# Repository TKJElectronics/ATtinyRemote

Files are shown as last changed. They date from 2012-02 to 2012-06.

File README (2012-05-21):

The code is released under the GNU General Public License.

This is a remote translator based on an ATtiny85. It translates commands from a Panasonic remote to specific JVC commands. This enables me to turn my JVC stereo on and off, mute it and turn the volume up or down, using my Panasonic remote for my TV.

A new version is now available, it can be found in the /ATtinyRemoteVer2 folder.

For more information see my blog post: http://blog.tkjelectronics.dk/2012/03/attinyremote/ or send me an email at kristianl at tkjelectronics dot dk.

The receiving code is based around Adafruit's IR-Commander sketch: https://github.com/adafruit/IR-Commander while the decoding of the Panasonic protocol and sending of the JVC commands are based upon this forked library: https://github.com/zenwheel/Arduino-IRremote. The originally library is by Ken Shirriff: https://github.com/shirriff/Arduino-IRremote

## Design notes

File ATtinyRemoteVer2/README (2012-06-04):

The code is released under the GNU General Public License.

This is a highly optimized version of the firmware. The code flow is basically the same as the first release.

The major difference is that it now uses a external interrupt for the receiving part. To tell the time I use timer0. It is used in CTC (Clear Timer on Compare Match Mode) every 6ms, as the maximum pulse i approximately 5ms. As the Panasonic protocol is very long (48 bits) is not necessary to check the length of the pulses very precisely, as my other IR remotes protocols' are only maximum 32 bits long. But it wouldn't be that hard to modify the code to work with any IR protocol.

Timer1 is used to send the IR commands. It is used in PWM mode, at a modulation frequency of 38kHz, but this can easily be modified.

I have also implemented a optional sleep mode, to save power consumption. This will set the microcontroller in power down mode.

For more information see my blog post: http://blog.tkjelectronics.dk/2012/03/attinyremote/ or send me an email at kristianl at tkjelectronics dot dk.

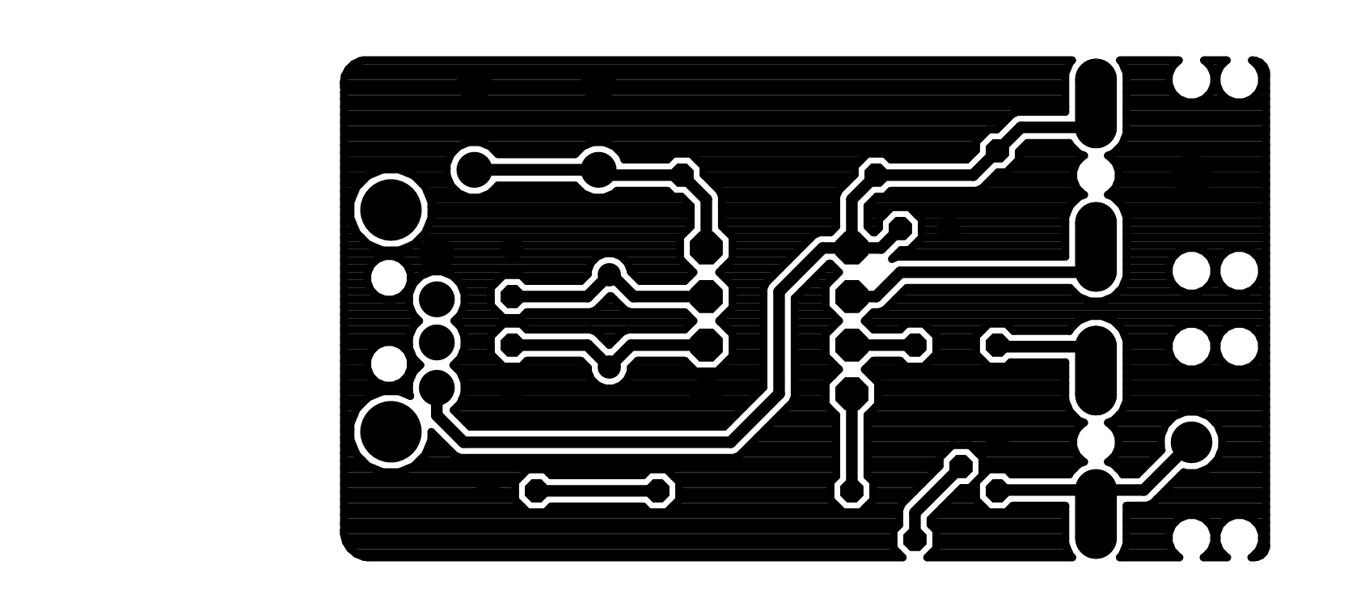
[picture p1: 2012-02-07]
PCB/Images for Gerber files/ATtinyRemote.bottomlayer.ger.png

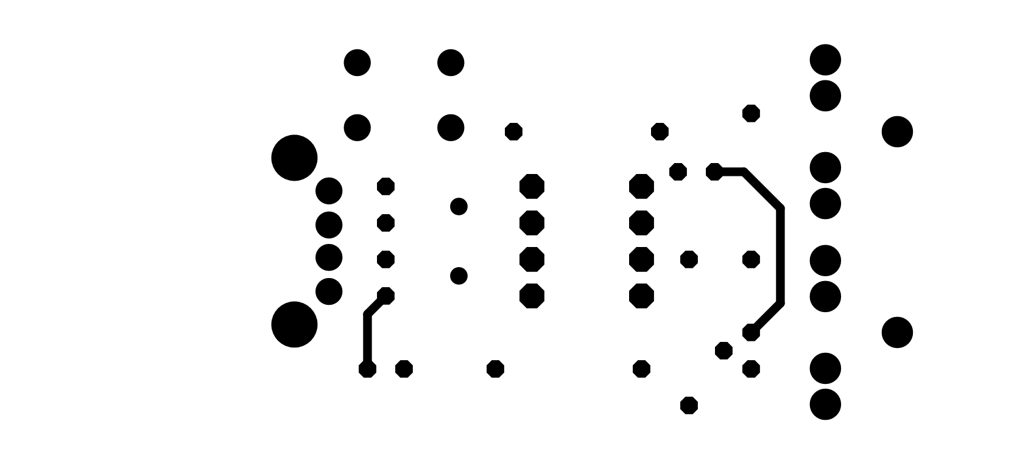
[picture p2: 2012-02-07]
PCB/Images for Gerber files/ATtinyRemote.toplayer.ger.png

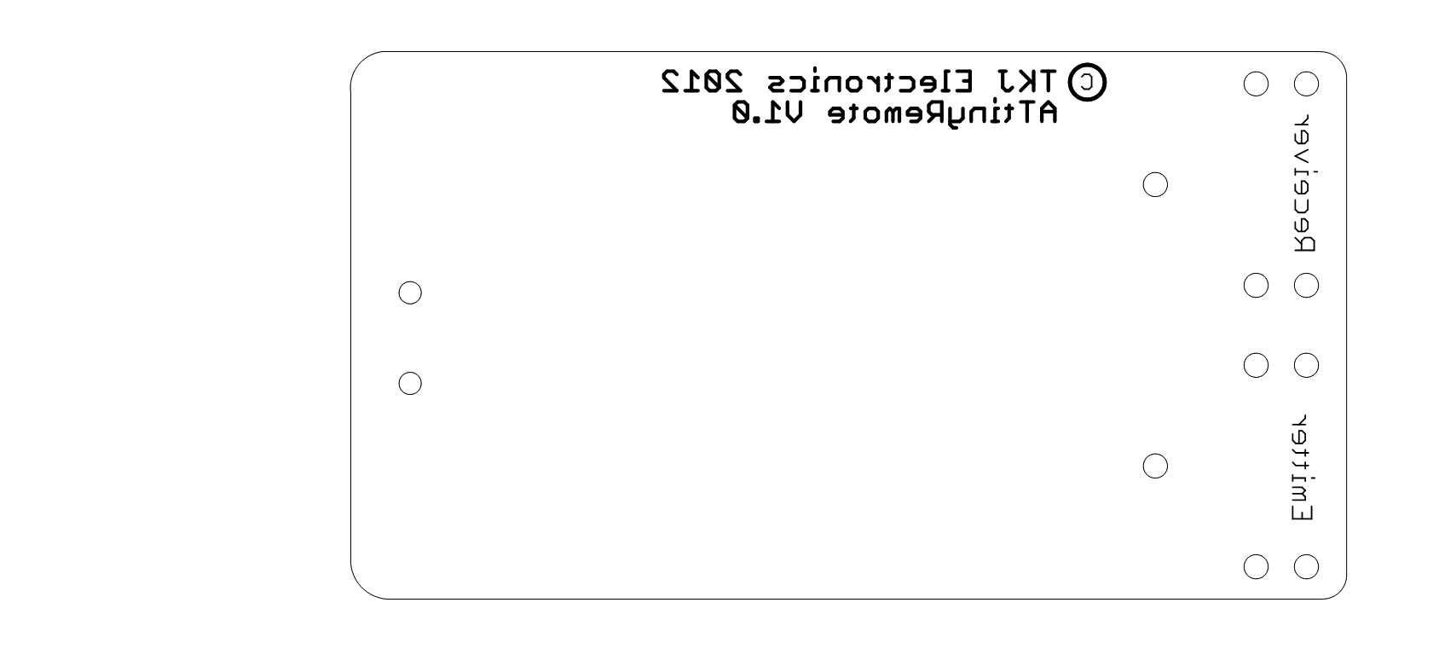
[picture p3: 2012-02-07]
PCB/Images for Gerber files/ATtinyRemote.bottomsilkscreen.ger.png

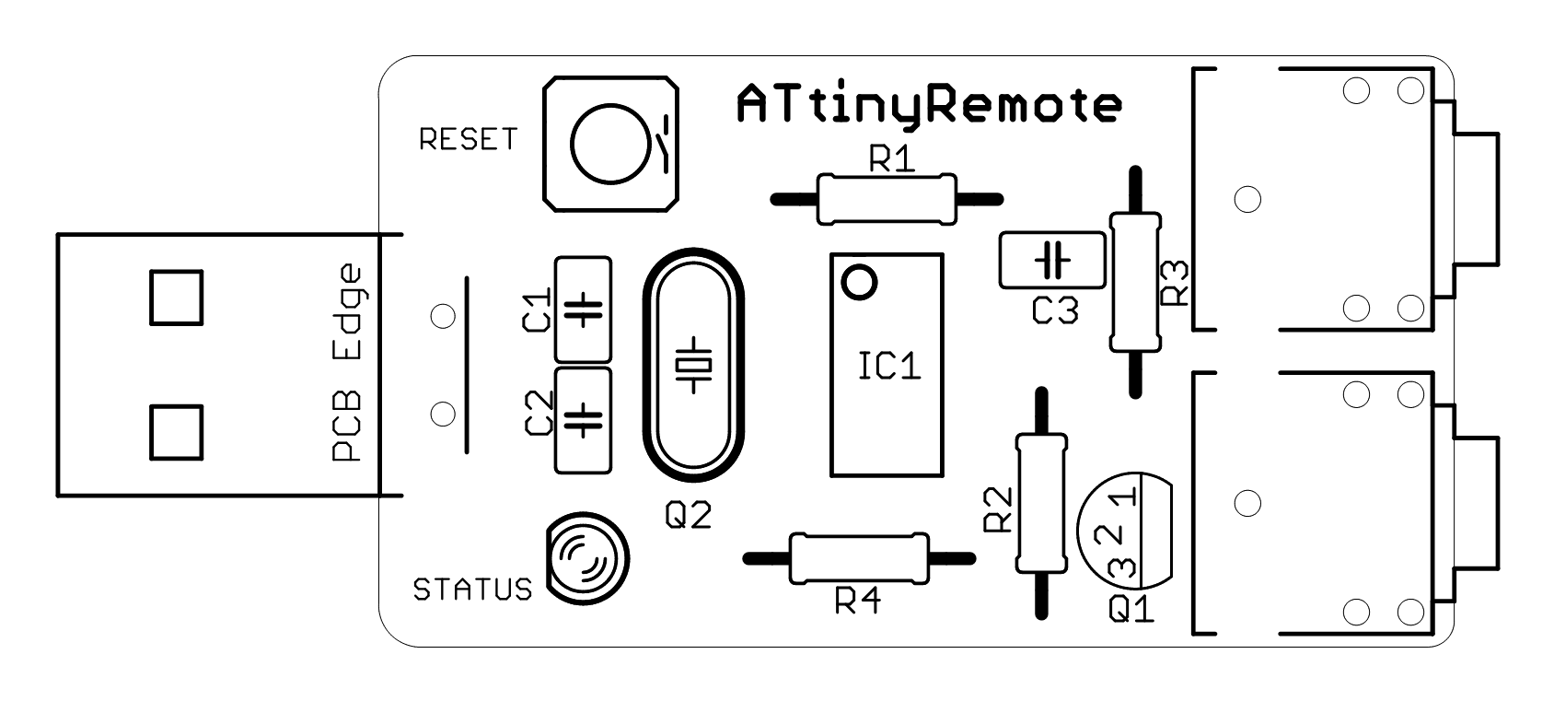
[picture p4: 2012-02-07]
PCB/Images for Gerber files/ATtinyRemote.topsilkscreen.ger.png

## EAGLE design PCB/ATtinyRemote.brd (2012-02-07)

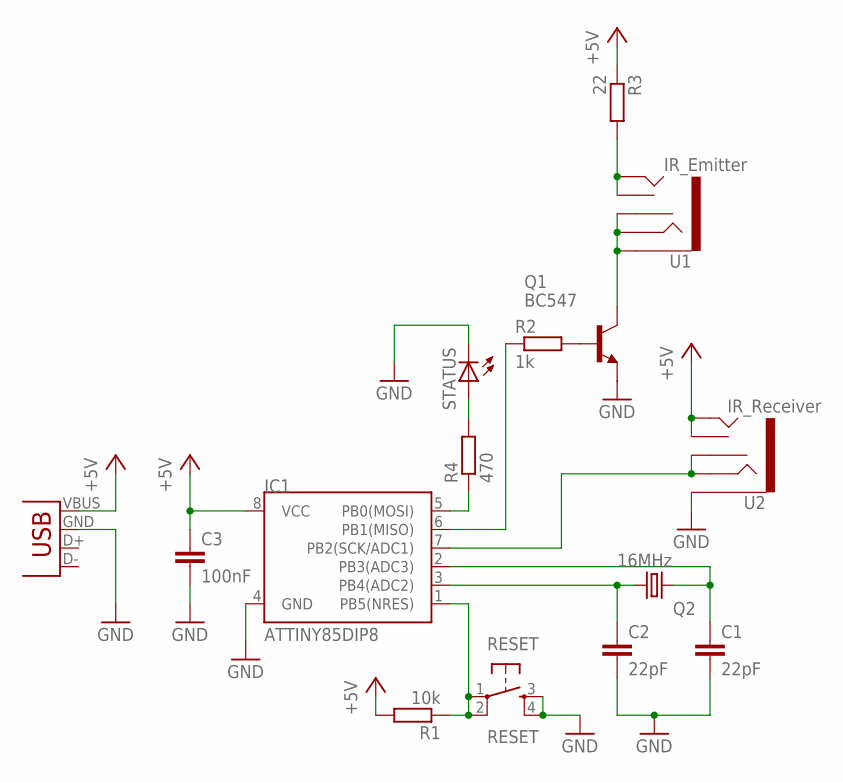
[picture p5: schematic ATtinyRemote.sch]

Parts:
C1, C2: 22pF; C025-025X050
C3: 100nF; C025-025X050
IC1: ATTINY85DIP8; DIP08
Q1: BC547; TO92
Q2: 16MHz; HC49/S
R1: 10k; 0207/10
R2: 1k; 0207/10
R3: 22; 0207/10
R4: 470; 0207/10
RESET: RESET; TACTILE-PTH
STATUS: LED3MM
U1: IR_Emitter; AUDIO-JACK
U2: IR_Receiver; AUDIO-JACK
X1: USB-A-H

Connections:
+5V: C3.1, IC1.8 (VCC), R1.2, R3.1, U2.TIP, U2.TSH, X1.VBUS (GND)
GND: C1.2, C2.2, C3.2, IC1.4 (GND), Q1.1 (E), RESET.3, RESET.4, STATUS.K (C), U2.SLEEVE, X1.GND (VBUS)
unnamed: C2.1, IC1.3 (PB4(ADC2)), Q2.1
unnamed: R3.2, U1.TIP, U1.TSH
unnamed: IC1.1 (PB5(NRES)), R1.1, RESET.1, RESET.2
unnamed: Q1.3 (C), U1.RING, U1.RSH, U1.SLEEVE
unnamed: IC1.7 (PB2(SCK/ADC1)), U2.RING, U2.RSH
unnamed: Q1.2 (B), R2.2
unnamed: IC1.6 (PB1(MISO)), R2.1
unnamed: R4.2, STATUS.A
unnamed: IC1.5 (PB0(MOSI)), R4.1
unnamed: C1.1, IC1.2 (PB3(ADC3)), Q2.2

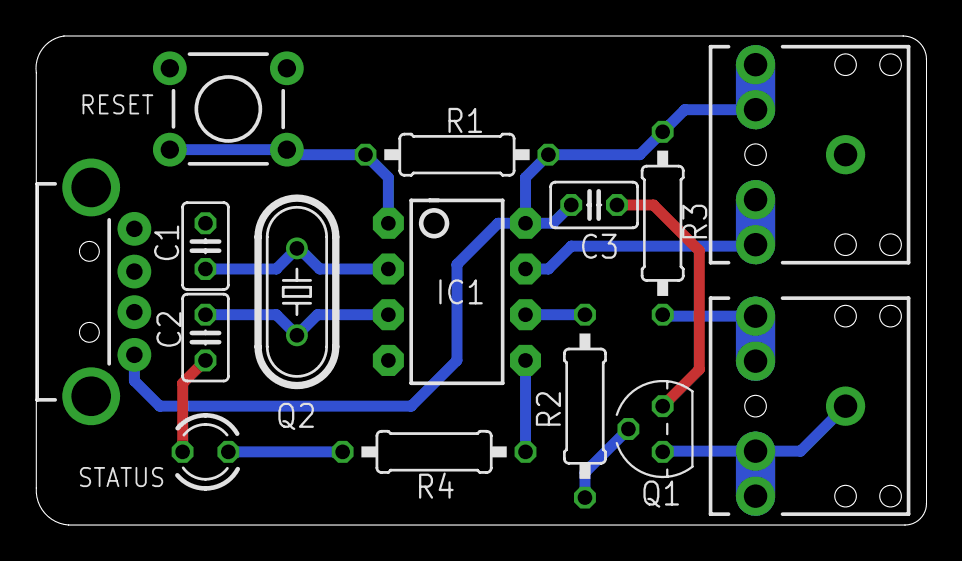
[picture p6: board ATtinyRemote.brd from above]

Board: 2 copper layers, 49.5 x 27.2 mm, 15 parts (0 on the bottom side), 12 nets.

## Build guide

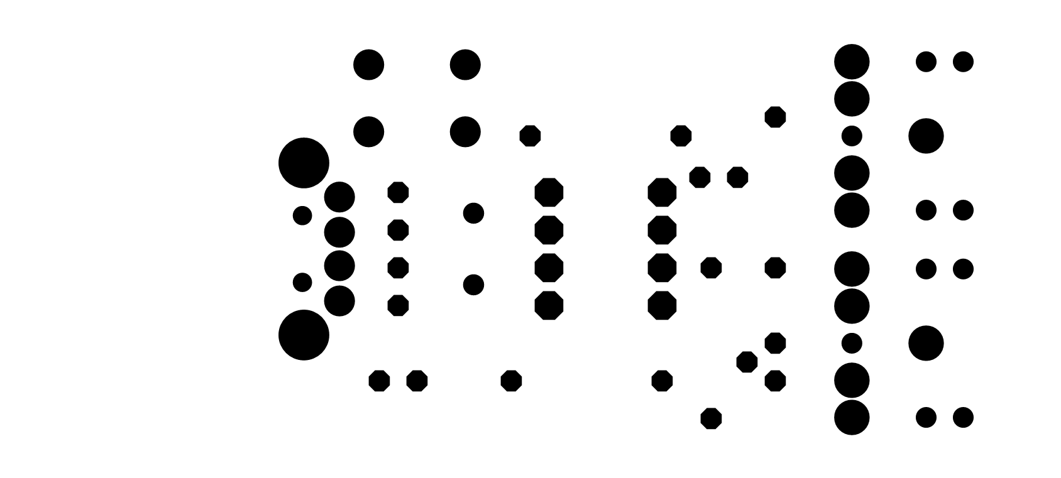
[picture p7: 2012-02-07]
PCB/Images for Gerber files/ATtinyRemote.bottomsoldermask.ger.png

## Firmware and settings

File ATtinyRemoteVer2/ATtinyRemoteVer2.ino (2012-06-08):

/*
 The fuses it set like so: -U lfuse:w:0xce:m -U hfuse:w:0xdc:m -U efuse:w:0xff:m
 This will set the ATtiny85 to use an external crystal at 8MHz or above
 The start-up time is set to 258 CK/14 CK + 4.1ms
 Brown-out detection is set to 4.3 and the SPI is enabled.
*/

//#define SLEEP // Uncomment this to save power, this will add a small delay after wake up, so fast presses wouldn't be decoded
#ifdef SLEEP
#include <avr/sleep.h> // Sleep mode is used between commands to save power
#endif

#include <avr/wdt.h> // Watchdog timer

#define LED    PINB0 // pin 5 on ATtiny85
#define IRLED  PINB1 // pin 6 on ATtiny85
#define IRRECV PINB2 // pin 7 on ATtiny85

#define PWMFREQUENCY  38000 // Frequency in Hz

/* The JVC Protocol is only 16-bits */
#define JVCPower        0xC5E8
#define JVCMute         0xC538
#define JVCVolumeDown   0xC5F8
#define JVCVolumeUp     0xC578

#define JVC_HDR_MARK    8000
#define JVC_HDR_SPACE   4000
#define JVC_BIT_MARK    600
#define JVC_ONE_SPACE   1600
#define JVC_ZERO_SPACE  550

#define MARK  (TCCR1 |= _BV(COM1A1)); // Enable pin 6 (PB1) PWM output
#define SPACE (TCCR1 &= ~(_BV(COM1A1))); // Disable pin 6 (PB1) PWM output

// The panasonic protocol is 48-bits long, all the commands has the same address (or pre data) and then followed by a 32 bit code
#define PanasonicAddress      0x4004     // Panasonic address (Pre data)
#define PanasonicPower        0x100BCBD  // Panasonic Power button
#define PanasonicPower2       0x1000E0F  // Red button - alternative power button
#define PanasonicMute         0x1008E8F  // Green button
#define PanasonicVolumeDown   0x1004E4F  // Yellow
#define PanasonicVolumeUp     0x100CECF  // Blue button
#define ATtinyPower           0x190CB5A  // Second power button

#define PANASONIC_BITS  48 // The Panasonic Protol is 48 bits long

#define COMPAREFREQUENCY (1000/6) // Frequency value equal to a compare match every 6ms - don't remove the parentheses or it won't compile correctly
#define TIMERVALUE (F_CPU/COMPAREFREQUENCY/1024-1) // See the datasheet page 75 - http://www.atmel.com/Images/doc2586.pdf - the equation is for a period, so don't divide by 2

volatile bool compareMatch = 0; // Used to indicate that a compare match has occurred
volatile uint16_t compareMatchCounter = 0; // Counter for every timer0 compare match

/*
 // pulse parameters in usec
 #define PANASONIC_HDR_MARK 3502
 #define PANASONIC_HDR_SPACE 1750
 #define PANASONIC_BIT_MARK 502
 #define PANASONIC_ONE_SPACE 1244
 #define PANASONIC_ZERO_SPACE 400
*/

#define headerTime  (TIMERVALUE*4000/6000) // 4000us
#define spaceTime   (TIMERVALUE*1324/6000) // (902+1746)/2=1324us

uint8_t IRState = 0;
uint8_t currentPulse = 0;
uint64_t IRBuffer = 0;
volatile uint64_t IRData = 0;
volatile bool finishedReading = 0;

bool deactivated = 0; // Used to disable the ATtinyRemote

void setup() {
  cli(); // Disables interrupts by setting the global interrupt mask

  /* Set up I/O's */
  DDRB |= _BV(LED); // Set as output
  DDRB |= _BV(IRLED); // Set as output
  PORTB &= ~(_BV(IRLED)); // When not sending PWM, we want it low
  DDRB &= ~(_BV(IRRECV)); // Set as input
  
  /* Disable Analog to Digitalconverter to save power */
  ADCSRA &= ~(_BV(ADEN));

  /* Set up timer0 to "Clear Timer on Compare Match (CTC) Mode" at a 6ms interval */
  TCCR0A = _BV(WGM01); // Set "Clear Timer on Compare Match (CTC) Mode" - OCR0A is TOP
  TCCR0B = _BV(CS02)| _BV(CS00); // Set precscaler to 1024
  OCR0A = TIMERVALUE; // Set the value, so there is a compare match every 6ms
  TIMSK = _BV(OCIE0A); //  Timer/Counter0 Output Compare Match A Interrupt Enable   

  /* Set up external interrupt on pin 7 */
  MCUCR |= _BV(ISC01); // The falling edge of INT0 generates an interrupt request
  MCUCR &= ~(_BV(ISC00));
  GIMSK = _BV(INT0); // External Interrupt Request 0 Enable

  /* Enable PWM with a frequency of 38kHz on pin 6 (OC1A) */
  TCCR1 = _BV(PWM1A) | _BV(CS12); // Enable PWM and set prescaler to 8
  OCR1C = (((F_CPU/8/PWMFREQUENCY))-1); // Set PWM Frequency to 38kHz, OCR1C is TOP, see the datasheet page 90
  OCR1A = OCR1C/3; // 33% duty cycle

  /* Enable watchdog timer at 4 seconds */
  wdt_enable(WDTO_4S);
  
  sei(); // Enables interrupts by setting the global interrupt mask  

  /* Indicate startup */
  PORTB |= _BV(LED); // Turn LED on
  newDelay(100);
  PORTB &= ~(_BV(LED)); // Turn LED off  
}

void loop() {
  wdt_reset(); // Reset watchdog timer
  
  if(finishedReading) {
    if((uint16_t)(IRData >> 32) == PanasonicAddress) {   
      if(deactivated) {
        if((uint32_t)IRData == ATtinyPower) {
          deactivated = false;
          PORTB &= ~(_BV(LED)); // Turn LED off          
          newDelay(250); // delay insures that it's just don't toggle "deactivate" very fast          
        }        
        finishedReading = 0; // Clear flag
      }
      else {
        switch((uint32_t)IRData) {
        case PanasonicVolumeUp:   
          JVCCommand(JVCVolumeUp,0);        
          break;
        case PanasonicVolumeDown:    
          JVCCommand(JVCVolumeDown,0);
          break;
        case PanasonicMute:
          JVCCommand(JVCMute,1);
          break;
        case PanasonicPower:
          JVCCommand(JVCPower,2);
          newDelay(3000); // On Panasonic TVs one have to hold the power button to turn the TV on, this delay keeps the ATtinyRemote from toggling the JVC stereo on and off
          finishedReading = 0; // Clear flag
          break;
        case PanasonicPower2:
          JVCCommand(JVCPower,1);
          break;
        case ATtinyPower: // This will disable the ATtinyRemote until the button is pressed again
          deactivated = true;
          PORTB |= _BV(LED); // Turn LED on          
          newDelay(250); // delay insures that it's just don't toggle "deactivate" very fast
          finishedReading = 0; // Clear flag
          break;
        default:
          finishedReading = 0; // Clear flag
          break;     
        }
      }       
#ifdef SLEEP // This can be enabled, but I decided not to, as it will miss the first command sent from the remote
      wdt_disable(); // Disable watchdog timer before going to sleep
      sleep(); // Put the device into sleep mode - the IR Receiver will trigger a external interrupt and wake the device
      wdt_enable(WDTO_4S); // Reenable watchdog timer
#endif
    } 
    else
      finishedReading = 0; // Clear flag
  }  
}

void newDelay(uint16_t time) { // I use my own simple delay, as I can't use delay() as it uses timer0 - delayMicroseconds() still work, as it uses assembly language, see https://github.com/arduino/Arduino/blob/master/hardware/arduino/cores/arduino/wiring.c
  compareMatchCounter = time/6; // Set number of counts - The input is in ms and the resolution is 6ms
  TCNT0 = 0; // Reset timer 
  while(compareMatchCounter);
}

void JVCCommand(uint16_t data, uint8_t waitForSend) {
  /* Don't wait until finished sending command before decoding next incomming data */
  if(!waitForSend)    
    finishedReading = 0; // Clear flag

  /* Send the command */
  uint16_t dataTemp; // Used to store data
  uint8_t nrRepeats; // Store the number of repeats  
  if(data == JVCVolumeUp || data == JVCVolumeDown) // Only send one repeat if it's a volume up or down command
    nrRepeats = 1;
  else
    nrRepeats = 5;

  /* Send Header */
  MARK
  delayMicroseconds(JVC_HDR_MARK);
  SPACE
  delayMicroseconds(JVC_HDR_SPACE);

  /* Send body */  
  for(uint8_t i = 0; i <= nrRepeats; i++) {
    dataTemp = data; // Store data
    for (uint8_t i = 0; i < 16; i++) {      
      MARK
      delayMicroseconds(JVC_BIT_MARK);
      SPACE
      if (dataTemp & 0x8000) // The data is send MSB      
        delayMicroseconds(JVC_ONE_SPACE); 
      else    
        delayMicroseconds(JVC_ZERO_SPACE);
      dataTemp <<= 1; // Shift data
    }
    MARK // Stop Mark
    delayMicroseconds(JVC_BIT_MARK);
    SPACE // Turn IR LED off  
    if(i != nrRepeats) // Don't make a delay, if it's the last repeat
      newDelay(20); // Wait 20 ms before sending again - this is actually not very precise if the flag has been reset, as the interrupt might reset the timer, but it works anyway
  }
  
  /* Wait until finished sending command before decoding next incomming data */
  if(waitForSend == 1)    
    finishedReading = 0; // Clear flag
    
  // waitForSend == 2, then it will not reset the data and set clear flag
}
/* 
  A mark sends an IR mark for the specified number of microseconds.
  The mark output is modulated at the PWM frequency.

  TCCR1 |= _BV(COM1A1);
  This will enable the pwm output:  
  OC1A cleared on compare match (TCNT1 = OCR1A). Set when TCNT1 = 0. 

  A space sends an IR space for the specified number of microseconds.
  A space is no output, so the PWM output is disabled.
   
  TCCR1 &= ~(_BV(COM1A1));  
  This wil disable the pwm output:  
  OC1A not connected.  
*/

ISR(INT0_vect) { // External interrupt at INT0  
  if(!finishedReading) { // Wait until the data has been read
    switch(IRState) {
    case 0:
      if(compareMatch) // First pulse after long pause
        IRState = 1;
      break;
    case 1:
      if(!compareMatch && TCNT0 > headerTime) { // Check if the pulse is not to long and it is longer than the headerTime
        currentPulse = 0; // Reset pulse counter
        IRBuffer = 0; // Reset buffer
        IRState = 2;
      } 
      else
        IRState = 0;
      break;
    case 2:
      if(compareMatch) // To long a pause, so it must be a gap
        IRState = 0;
      else {
        if(TCNT0 < spaceTime) // Check if it's a mark
          IRBuffer <<= 1;       
        else // It must be a space
          IRBuffer = (IRBuffer << 1) | 1;
        currentPulse++;          
        if (currentPulse == PANASONIC_BITS) { // All bits have been received
          IRData = IRBuffer;
          finishedReading = 1; // Indicate that the reading is finished, this has to be cleared in software
          IRState = 0; // Reset IR state for next command
        }                
      }
      break;
    }
    TCNT0 = 0; // Clear timer, don't clear if the data is been read, as the timer is used by newDelay()
  }  
  compareMatch = 0; // Clear flag
}
ISR(TIM0_COMPA_vect) { // Timer0/Counter Compare Match A
  //PORTB ^= _BV(LED); // Used to check the timing with my oscilloscope
  compareMatch = 1; // It has been more than 6ms since last pulse were received
  compareMatchCounter--; // Used for newDelay()
}
#ifdef SLEEP
void sleep() { // The ATtiny85 is woken by a external interrupt on INT0 from the IR REceiver
  //PORTB &= ~(_BV(LED)); // Turn off LED when it goes to sleep

  // The falling edge of INT0 generates an interrupt request. 
  MCUCR &= ~(_BV(ISC00) | _BV(ISC01)); // To wake up from Power-down, only level interrupt for INT0 can be used.    

  set_sleep_mode(SLEEP_MODE_PWR_DOWN); // Set sleep mode
  sleep_mode(); // Here the device is put to sleep
  
  TCNT0 = 0; // Clear timer
  compareMatch = 0; // Clear flag
  
  // Disable level interrupt and set back to falling edge interrupt
  MCUCR |= _BV(ISC01); // The falling edge of INT0 generates an interrupt request 

  //PORTB |= _BV(LED); // Turn it back on
}
#endif

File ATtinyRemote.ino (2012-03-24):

/* 
 * The code is released under the GNU General Public License.
 * Developed by Kristian Lauszus
 * This is a remote translator based on an ATtiny85. 
 * It translates commands from a Panasonic remote to specific JVC commands. 
 * This enables me to turn my JVC stereo on and off, mute it and turn the volume up or down, using my Panasonic remote for my TV.
 * For details, see http://blog.tkjelectronics.dk
 */

#include "IRremote.h"

#define JVCPower              0xC5E8
#define JVCMute               0xC538
#define JVCVolumeUp           0xC578
#define JVCVolumeDown         0xC5F8

//The panasonic protocol is 48-bits long, all the commands has the same address (or pre data) and then followed by a 32 bit code
#define PanasonicAddress      0x4004     // Panasonic address (Pre data)
#define PanasonicPower        0x100BCBD  // Panasonic Power button
#define PanasonicPower2       0x1000E0F  // Red button - alternative power button
#define PanasonicMute         0x1008E8F  // Green button
#define PanasonicVolumeDown   0x1004E4F  // Yellow
#define PanasonicVolumeUp     0x100CECF  // Blue button
#define ATtinyPower           0x190CB5A  // Second power button

#define IRrecv PB2 // pin 7 on ATtiny85

IRsend irsend;

// The amount of time between each measurement in microseconds
#define RESOLUTION 10

// the maximum pulse we'll listen for - maximum pulse is 3502us, so 5000us should be way over the top
#define MAXPULSE (5000/RESOLUTION)

// What percent we will allow in variation to match the same code - this large tolerance will ensure that the data is decoded correct even at a far distance
#define TOLERANCE 40 // 40 % tolerance

// we will store up to 50 pulse pairs  - the Panasonic protocol is 48 bits long or 96 pairs excluding header (2 pairs)
#define commandLength 50
uint16_t pulses[commandLength][2];  // pair is high and low pulse

#define RED PB0 // pin 5 on ATtiny85

uint16_t IRaddress;
uint32_t IRdata;
boolean deactivated;

void setup(void) 
{
  irsend.enableIROut(38); // Enable phase-correct PWM with a frequency of 38kHz
  DDRB |= _BV(RED); // Set as output
  DDRB &= ~(_BV(IRrecv)); // Set as input

  PORTB |= _BV(RED); // Turn LED on
  delay(100);
  PORTB &= ~(_BV(RED)); // Turn LED off 
}

void loop(void) {  
  if(listenForIR())
  {
    if(decodeIR() && IRaddress == PanasonicAddress)
    {
      if(deactivated)
      {
        if(IRdata == ATtinyPower)
        {
          deactivated = false;
          PORTB &= ~(_BV(RED)); // Turn LED off
          delay(250); // delay insures that it's just don't toggle "deactivate" very fast
        }
      }
      else
      {
        switch(IRdata)
        {      
        case PanasonicVolumeUp:   
          JVCCommand(JVCVolumeUp);        
          break;
        case PanasonicVolumeDown:    
          JVCCommand(JVCVolumeDown);  
          break;
        case PanasonicMute:
          JVCCommand(JVCMute);
          break;
        case PanasonicPower:
          JVCCommand(JVCPower);
          delay(3000); // On Panasonic TVs one have to hold the power button to turn the TV on, this delay keeps the ATtinyRemote from toggling the JVC stereo on and off
          break;
        case PanasonicPower2:
          JVCCommand(JVCPower);
          break;
        case ATtinyPower: // This will disable the ATtinyRemote until the button is pressed again
          deactivated = true;
          PORTB |= _BV(RED); // Turn LED on
          delay(250); // delay insures that it's just don't toggle "deactivate" very fast
          break;
        default:
          break;     
        }
      }
    }
  }
}

void JVCCommand(uint16_t data)
{
  uint8_t nrRepeats;  
  if(data == JVCVolumeUp || data == JVCVolumeDown) // Only send once if it's a volume up or down command
    nrRepeats = 1;
  else
    nrRepeats = 5;
    
  irsend.sendJVC(data, 16,0); // hex value, 16 bits, no repeat
  for(uint8_t i = 0; i < nrRepeats; i++) {    
    delayMicroseconds(50); // see http://www.sbprojects.com/knowledge/ir/jvc.php for information
    irsend.sendJVC(data, 16,1); // hex value, 16 bits, repeat        
  }
}

boolean MATCH(uint16_t measured, uint16_t desired) // True if the condition are met
{
  measured *= RESOLUTION;
  return (measured >= desired-((float)desired*TOLERANCE/100) && measured <= desired+((float)desired*TOLERANCE/100));  
}

boolean decodeIR(void) {  
  unsigned long long data = 0;

  if(!MATCH(pulses[0][1],PANASONIC_HDR_MARK))
    return false;
  if(!MATCH(pulses[0+1][0],PANASONIC_HDR_SPACE))
    return false;
  for (int i=0; i < PANASONIC_BITS; i++) 
  {
    if(!MATCH(pulses[i+1][1],PANASONIC_BIT_MARK))
    {
      if(!MATCH(pulses[i+1][1],PANASONIC_BIT_MARK-252)) // Small hack to make it work at a far distance
        return false;
    }
    if(MATCH(pulses[i+2][0],PANASONIC_ONE_SPACE))
      data = (data << 1) | 1;
    else if (MATCH(pulses[i+2][0],PANASONIC_ZERO_SPACE))
      data <<= 1;
    else // It's neither 0 or 1, so something went wrong
      return false;
  }
  IRaddress = (uint16_t)(data >> 32);
  IRdata = (uint32_t)data;
  return true;
}

boolean listenForIR(void) {
  uint8_t currentpulse = 0; // index for pulses we're storing
  while (1) {    
    uint16_t highpulse, lowpulse;  // temporary storage timing
    highpulse = lowpulse = 0; // start out with no pulse length

    while (PINB & _BV(IRrecv)) {
      // pin is still HIGH
      highpulse++;// count off another few microseconds
      delayMicroseconds(RESOLUTION);
      // If the pulse is too long, we 'timed out' - either nothing
      // was received or the code is finished, so print what
      // we've grabbed so far, and then reset
      if (highpulse >= MAXPULSE && currentpulse != 0)
        return false;        
    }
    // we didn't time out so lets stash the reading
    pulses[currentpulse][0] = highpulse;

    // same as above
    while (!(PINB & _BV(IRrecv))) {
      // pin is still LOW
      lowpulse++;
      delayMicroseconds(RESOLUTION);
      if (lowpulse >= MAXPULSE && currentpulse != 0)
        return false;
    }
    pulses[currentpulse][1] = lowpulse;

    // we read one high-low pulse successfully, continue!
    currentpulse++;

    if(currentpulse == commandLength) // Exit when the full command has been received
      return true;
  }
}

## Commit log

2012-01-29 Schematic and layout added
    [ATtinyRemote.brd, ATtinyRemote.sch]
2012-02-07 Minor adjustments to make it work better in practice
    [ATtinyRemote.brd, ATtinyRemote.sch]
2012-02-07 Fixed silkscreen
    [ATtinyRemote.brd]
2012-02-07 Version 1.0 of the PCB
    Gerber files for http://www.dorkbotpdx.org/wiki/pcb_order
    [ATtinyRemote.brd, ATtinyRemote.sch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]
2012-03-24 Send multiple times when power on/off and muting
2012-05-21 A highly optimized version has been added
    use timer0. It is used in CTC (Clear Timer on Compare Match Mode) every
    6ms, as the maximum pulse i approximately 5ms. As the Panasonic
    protocol is very long (48 bits) is not necessary to check the length of
    the pulses very precisely, as my other IR remotes protocols' are only
    maximum 32 bits long. But it wouldn't be that hard to modify the code
    to work with any IR protocol.
2012-06-04 Call stack overflow has know been fixed
    The ATtiny85 sometimes freezer up - I think it ran out of RAM - I
    suspect the calling of JVCCommand() which called sendJVC() that then
    called mark() and space() several times. Therefore it has now been
    implemented in the same function.
    As a bonus, the program also works much faster now.
    [ATtinyRemoteVer2.ino]
2012-06-05 Added watchdog timer
2012-06-05 Fixed some potential bugs
    [ATtinyRemoteVer2.ino]
2012-06-05 Found bug that caused the hang up
    Actually the watchdog timer is not necessary, as I included it, because
    I thought that the problem might be a hang up in the newDelay function,
    but I will just keep it there anyway.
    [ATtinyRemoteVer2.ino]

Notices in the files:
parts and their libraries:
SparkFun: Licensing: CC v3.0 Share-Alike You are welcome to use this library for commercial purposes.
